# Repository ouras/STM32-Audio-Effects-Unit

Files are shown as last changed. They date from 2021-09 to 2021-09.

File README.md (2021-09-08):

# STM32-Audio-Effects-Unit

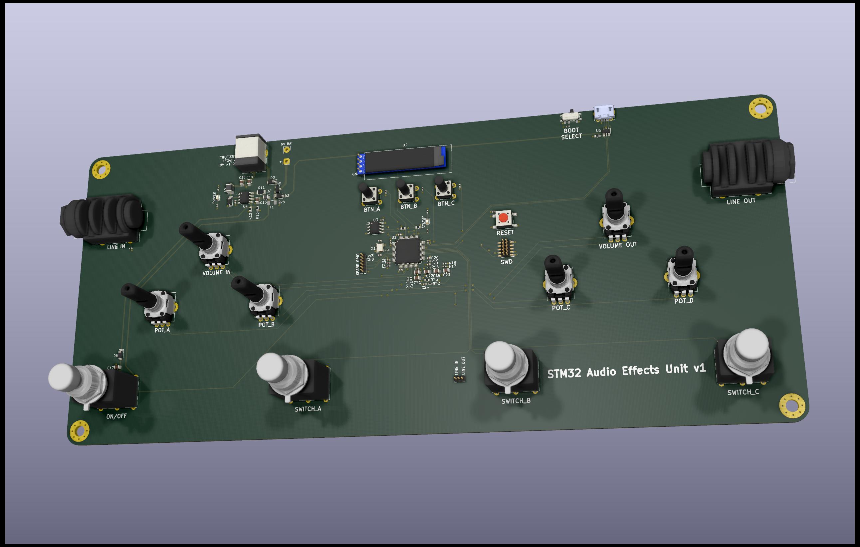
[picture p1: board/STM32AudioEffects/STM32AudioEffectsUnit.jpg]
Board v1


Audio effects unit designed for STM32. Includes:
- Library of effects implemented in C (including distortion/overdrive, reverb/echo, and compression)
- Python GUI demo/testbench for effects (based on PyQt, PyPlot, NumPy, and ctypes)
- PCB layout based on STM32F3RETx (plus LTSpice files for select sub-networks)
- CubeMX file for board (including FreeRTOS, peripheral, and pin configuration)
- main.c (FreeRTOS-based firmware)

Firmware features:
- FreeRTOS for task management
- ADC and DAC with DMA for efficient audio processing (note: sample rate = 40.5 kHz)
- I2C for EEPROM ~~and OLED display~~ *(coming soon)*
- Interrupts/handlers for user inputs

Board includes:
- 1/4" (6.35mm) input/output jacks
- OLED display
- 4 configuration potentiometers + 2 volume potentiometers
- 3 buttons
- 3 switches
- EEPROM (for user configuration backups)
- Input and output active gain and noise filter networks (with LTSpice schematics/simulation files)
- 9V DC wall adapter, 9V battery, and 5V USB power support (converted to 3.3V for Vcc)
- Status and power LEDs

Directory guide:
- /board contains LTSpice files and a KiCad project for the board
- /cubemx contains a CubeMX file for generating code for the MCU configuration and a main.c file containing the FreeRTOS port
- /demo contains files for running the demo
- /effects and /math contain the effects and math libraries
- /signal_gen_tools contains code for generating binary samples files

Running the demo:
1. Copy the contents of /demo to a folder.
2. Install the required modules (at the top of effects.py and main.py)
3. Copy the contents of /math and /effects to the folder from step 1.
4. Compile the C source files using:
  1. gcc -Wall -c fast_math.c effects.c
5. Create the shared library using:
  1. gcc -shared -o libeffects.dll \*.o
  2. Add “-m64” if using 64-bit Python
  3. Run main.py

A working document for this project (which include requirements, milestones, and technical notes) can be found [here](https://docs.google.com/document/d/13bzRhMHOJ_USe95iWY26JIxKYx1gLJ1tkpusW1AXwGo/edit?usp=sharing).

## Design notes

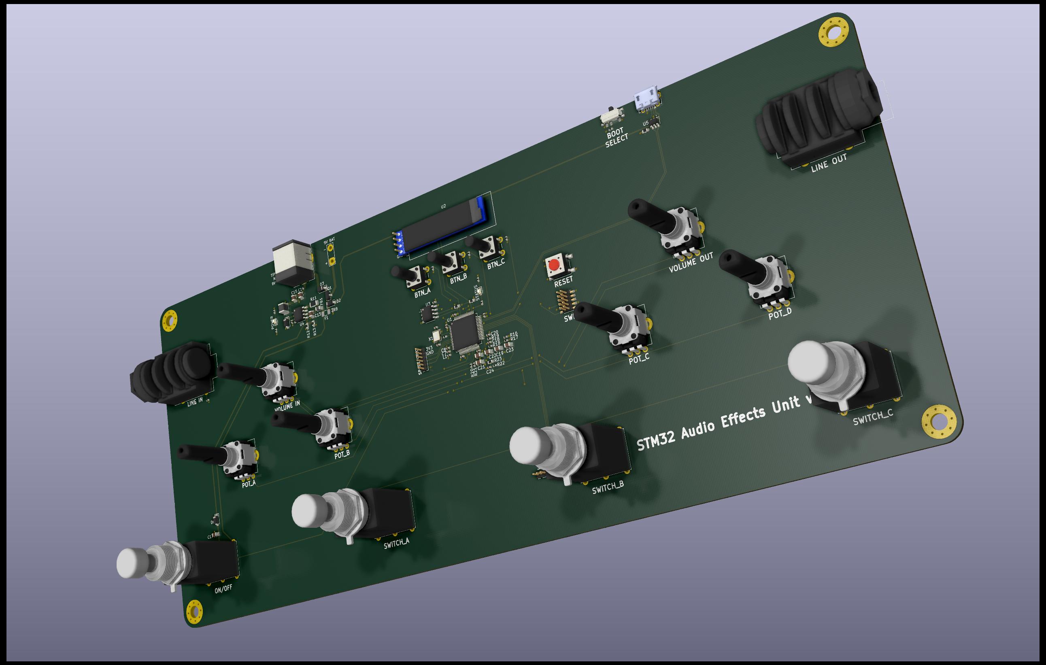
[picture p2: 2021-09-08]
board/STM32AudioEffects/STM32AudioEffects.jpg

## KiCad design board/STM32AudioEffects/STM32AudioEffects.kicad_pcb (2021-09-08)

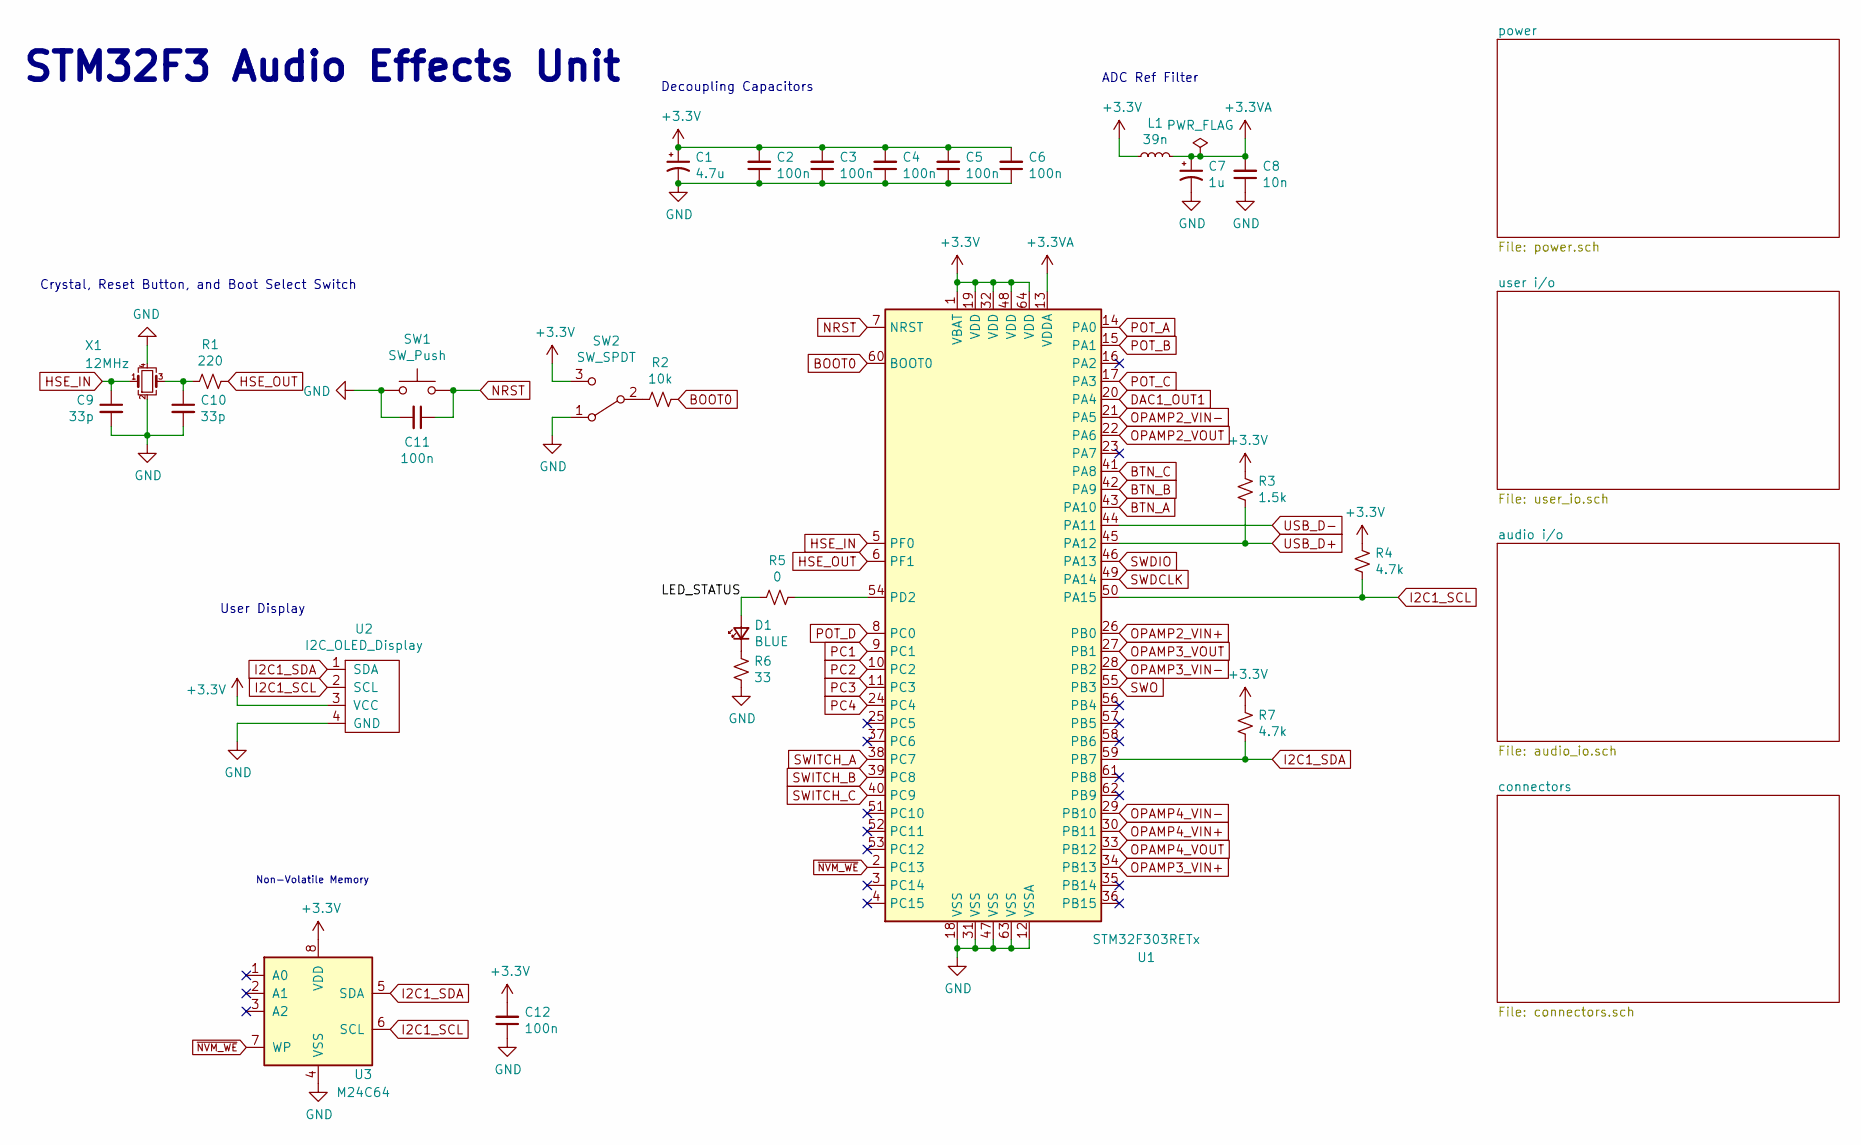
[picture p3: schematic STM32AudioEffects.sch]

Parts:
C1: 4.7u; C_0805_2012Metric
C2, C3, C4, C5, C6, C11, C12: 100n; C_0402_1005Metric
C7: 1u; C_0402_1005Metric
C8: 10n; C_0402_1005Metric
C9, C10: 33p; C_0402_1005Metric
D1: BLUE; LED_0603_1608Metric
L1: 39n; L_0402_1005Metric
R1: 220; R_0402_1005Metric
R2: 10k; R_0402_1005Metric
R3: 1.5k; R_0603_1608Metric
R4, R7: 4.7k; R_0603_1608Metric
R5: 0; R_0402_1005Metric
R6: 33; R_0402_1005Metric
SW1: SW_Push; SW_SPST_PTS645
SW2: SW_SPDT; SW_SPDT_PCM12
U1: STM32F303RETx; LQFP-64_10x10mm_P0.5mm
U2: I2C_OLED_Display; I2C_OLED_DISPLAY
U3: M24C64; SOIC-8_3.9x4.9mm_P1.27mm
X1: 12MHz; Crystal_SMD_3225-4Pin_3.2x2.5mm

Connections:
+3.3VA: C7.1, C8.2, L1.2, U1.13 (VDDA)
+3V3: C1.1, C2.2, C3.2, C4.2, C5.2, C6.2, C12.2, L1.1, R3.1, R4.1, R7.1, SW2.3 (C), U1.1 (VBAT), U1.19 (VDD), U1.32 (VDD), U1.48 (VDD), U1.64 (VDD), U2.3 (VCC), U3.8 (VDD); also elsewhere on the board
/LED_STATUS: D1.2 (A), R5.2
BOOT0: R2.1, U1.60 (BOOT0)
BTN_A: U1.43 (PA10); also elsewhere on the board
BTN_B: U1.42 (PA9); also elsewhere on the board
BTN_C: U1.41 (PA8); also elsewhere on the board
DAC1_OUT1: U1.20 (PA4); also elsewhere on the board
GND: C1.2, C2.1, C3.1, C4.1, C5.1, C6.1, C7.2, C8.1, C9.2, C10.2, C11.2, C12.1, R6.2, SW1.1, SW2.1 (A), U1.12 (VSSA), U1.18 (VSS), U1.31 (VSS), U1.47 (VSS), U1.63 (VSS), U2.4 (GND), U3.4 (VSS), X1.2, X1.4; also elsewhere on the board
HSE_IN: C9.1, U1.5 (PF0), X1.1
HSE_OUT: R1.1, U1.6 (PF1)
I2C1_SCL: R4.2, U1.50 (PA15), U2.2 (SCL), U3.6 (SCL)
I2C1_SDA: R7.2, U1.59 (PB7), U2.1 (SDA), U3.5 (SDA)
NRST: C11.1, SW1.2, U1.7 (NRST); also elsewhere on the board
unnamed: C10.1, R1.2, X1.3
unnamed: D1.1 (K), R6.1
unnamed: R2.2, SW2.2 (B)
unnamed: R5.1, U1.54 (PD2)
OPAMP2_VIN+: U1.26 (PB0); also elsewhere on the board
OPAMP3_VIN+: U1.34 (PB13); also elsewhere on the board
OPAMP3_VIN-: U1.28 (PB2); also elsewhere on the board
OPAMP3_VOUT: U1.27 (PB1); also elsewhere on the board
OPAMP4_VIN+: U1.30 (PB11); also elsewhere on the board
OPAMP4_VIN-: U1.29 (PB10), U1.33 (PB12); also elsewhere on the board
PC1: U1.9 (PC1); also elsewhere on the board
PC2: U1.10 (PC2); also elsewhere on the board
PC3: U1.11 (PC3); also elsewhere on the board
PC4: U1.24 (PC4); also elsewhere on the board
POT_A: U1.14 (PA0); also elsewhere on the board
POT_B: U1.15 (PA1); also elsewhere on the board
POT_C: U1.17 (PA3); also elsewhere on the board
POT_D: U1.8 (PC0); also elsewhere on the board
SWDCLK: U1.49 (PA14); also elsewhere on the board
SWDIO: U1.46 (PA13); also elsewhere on the board
SWITCH_A: U1.38 (PC7); also elsewhere on the board
SWITCH_B: U1.39 (PC8); also elsewhere on the board
SWITCH_C: U1.40 (PC9); also elsewhere on the board
SWO: U1.55 (PB3); also elsewhere on the board
USB_D+: R3.2, U1.45 (PA12); also elsewhere on the board
USB_D-: U1.44 (PA11); also elsewhere on the board
~NVM_WE: U1.2 (PC13), U3.7 (WP)

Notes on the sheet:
ADC Ref Filter
Decoupling Capacitors
Crystal, Reset Button, and Boot Select Switch
User Display
STM32F3 Audio Effects Unit
Non-Volatile Memory

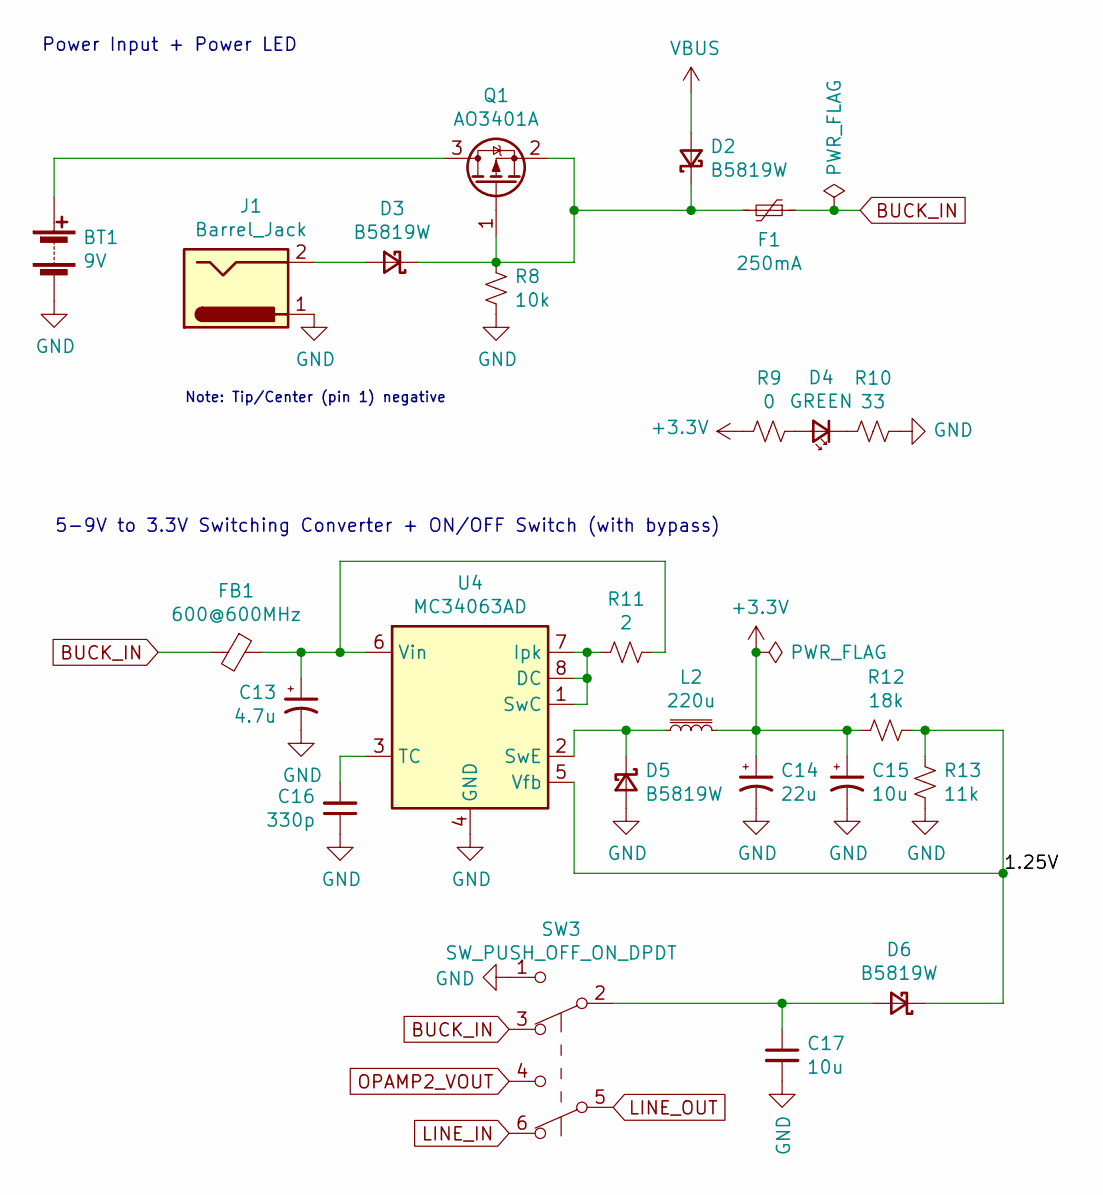
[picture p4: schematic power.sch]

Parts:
BT1: 9V; TestPoint_2Pads_Pitch5.08mm_Drill1.3mm
C13: 4.7u; C_0805_2012Metric
C14: 22u; C_0805_2012Metric
C15, C17: 10u; C_0805_2012Metric
C16: 330p; C_0402_1005Metric
D2, D3, D5, D6: B5819W; D_SOD-123
D4: GREEN; LED_0603_1608Metric
F1: 250mA; Fuse_1206_3216Metric
FB1: 600@600MHz; L_0805_2012Metric
J1: Barrel_Jack; BarrelJack_CUI_PJ-063AH_Horizontal
L2: 220u; L_1210_3225Metric
Q1: AO3401A; SOT-23
R8: 10k; R_0402_1005Metric
R9: 0; R_0402_1005Metric
R10: 33; R_0402_1005Metric
R11: 2; R_1206_3216Metric
R12: 18k; R_0603_1608Metric
R13: 11k; R_0603_1608Metric
SW3: SW_PUSH_OFF_ON_DPDT; SW_DPDT_FOOT_17.2x12.2mm_Vertical
U4: MC34063AD; SOIC-8_3.9x4.9mm_P1.27mm

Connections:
+3V3: C14.1, C15.1, L2.2, R9.1, R12.2; also elsewhere on the board
/power/1.25V: D6.1 (K), R12.1, R13.1, U4.5 (Vfb)
BUCK_IN: F1.1, FB1.2, SW3.3 (A)
GND: BT1.2 (-), C13.2, C14.2, C15.2, C16.1, C17.2, D5.2 (A), J1.1, R8.2, R10.2, R13.2, SW3.1 (C), U4.4 (GND); also elsewhere on the board
LINE_IN: SW3.6 (A); also elsewhere on the board
LINE_OUT: SW3.5 (B); also elsewhere on the board
unnamed: BT1.1 (+), Q1.3 (D)
unnamed: C13.1, FB1.1, R11.1, U4.6 (Vin)
unnamed: C16.2, U4.3 (TC)
unnamed: C17.1, D6.2 (A), SW3.2 (B)
unnamed: D2.1 (K), D3.1 (K), F1.2, Q1.1 (G), Q1.2 (S), R8.1
unnamed: D3.2 (A), J1.2
unnamed: D4.1 (K), R10.1
unnamed: D4.2 (A), R9.2
unnamed: D5.1 (K), L2.1, U4.2 (SwE)
unnamed: R11.2, U4.1 (SwC), U4.7 (Ipk), U4.8 (DC)
VBUS: D2.2 (A); also elsewhere on the board

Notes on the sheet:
Power Input + Power LED
5-9V to 3.3V Switching Converter + ON/OFF Switch (with bypass)
Note: Tip/Center (pin 1) negative

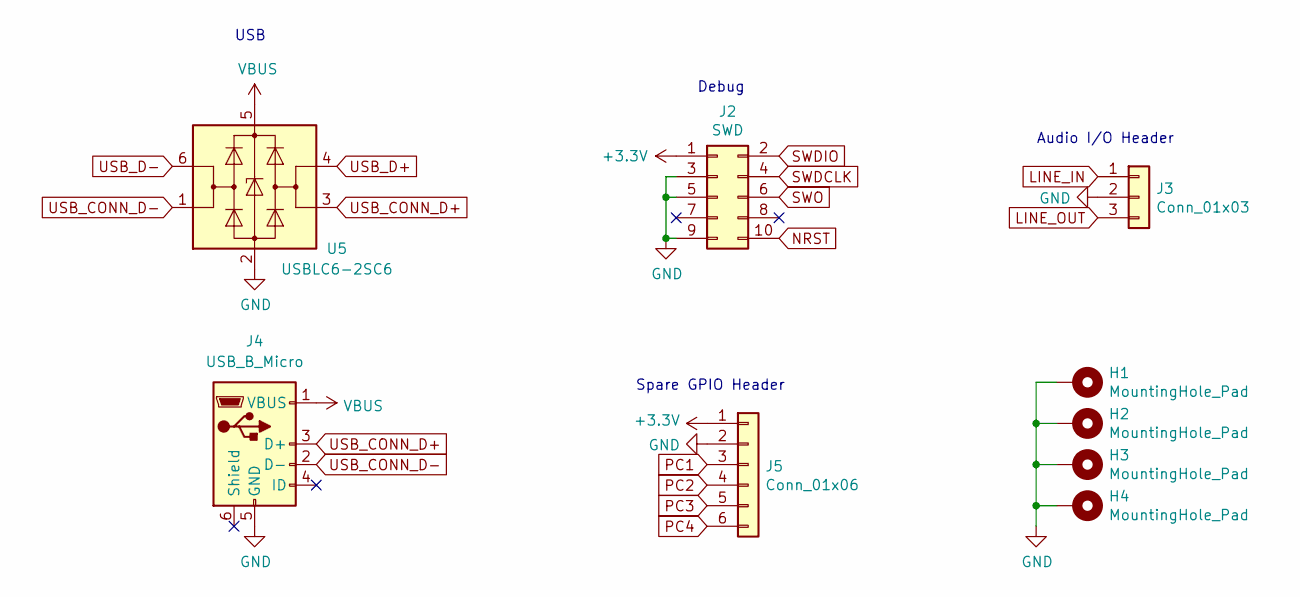
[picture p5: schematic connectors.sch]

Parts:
H1, H2, H3, H4: MountingHole_Pad; MountingHole_4.3mm_M4_Pad_Via
J2: SWD; PinHeader_2x05_P1.27mm_Vertical_SMD
J3: Conn_01x03; PinHeader_1x03_P1.27mm_Vertical
J4: USB_B_Micro; USB_Micro-B_Molex-105017-0001
J5: Conn_01x06; PinHeader_1x06_P1.27mm_Vertical
U5: USBLC6-2SC6; SOT-23-6

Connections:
+3V3: J2.1, J5.1; also elsewhere on the board
GND: H1.1, H2.1, H3.1, H4.1, J2.3, J2.5, J2.9, J3.2, J4.5 (GND), J5.2, U5.2 (GND); also elsewhere on the board
LINE_IN: J3.1; also elsewhere on the board
LINE_OUT: J3.3; also elsewhere on the board
NRST: J2.10; also elsewhere on the board
PC1: J5.3; also elsewhere on the board
PC2: J5.4; also elsewhere on the board
PC3: J5.5; also elsewhere on the board
PC4: J5.6; also elsewhere on the board
SWDCLK: J2.4; also elsewhere on the board
SWDIO: J2.2; also elsewhere on the board
SWO: J2.6; also elsewhere on the board
USB_CONN_D+: J4.3 (D+), U5.3 (I/O2)
USB_CONN_D-: J4.2 (D-), U5.1 (I/O1)
USB_D+: U5.4 (I/O2); also elsewhere on the board
USB_D-: U5.6 (I/O1); also elsewhere on the board
VBUS: J4.1 (VBUS), U5.5 (VBUS); also elsewhere on the board

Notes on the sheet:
USB
Debug
Spare GPIO Header
Audio I/O Header

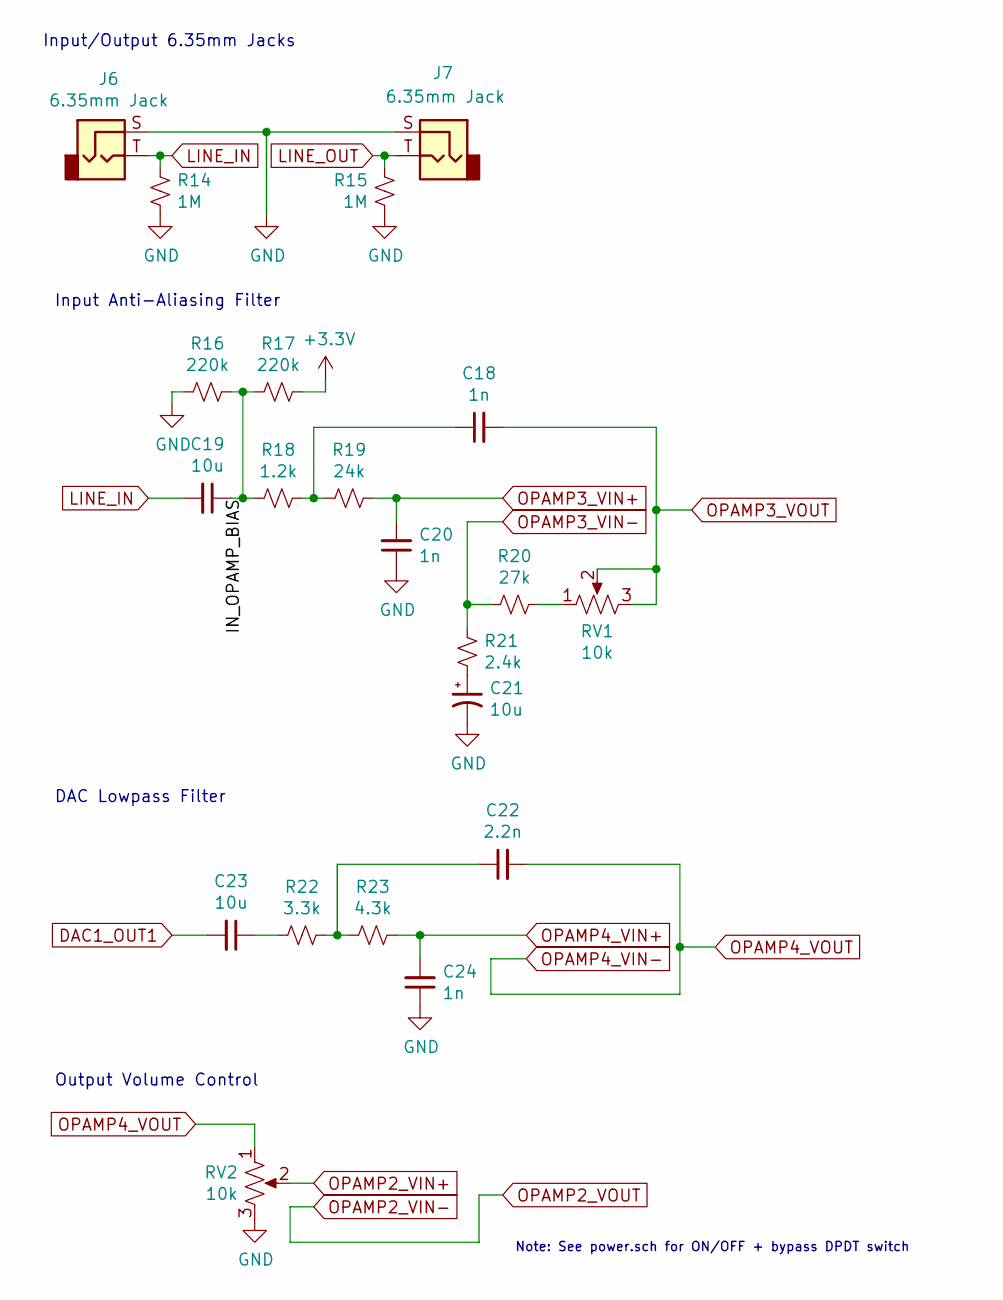
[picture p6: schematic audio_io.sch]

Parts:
C18, C20, C24: 1n; C_0402_1005Metric
C19, C21, C23: 10u; C_0805_2012Metric
C22: 2.2n; C_0805_2012Metric
J6, J7: 6.35mm Jack; Jack_6.35mm_Neutrik_NMJ4HFD2_Horizontal
R14, R15: 1M; R_0402_1005Metric
R16, R17: 220k; R_0402_1005Metric
R18: 1.2k; R_0402_1005Metric
R19: 24k; R_0402_1005Metric
R20: 27k; R_0402_1005Metric
R21: 2.4k; R_0402_1005Metric
R22: 3.3k; R_0402_1005Metric
R23: 4.3k; R_0603_1608Metric
RV1, RV2: 10k; Potentiometer_Alps_RK09K_Single_Vertical

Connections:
+3V3: R17.1; also elsewhere on the board
/audio i/o/IN_OPAMP_BIAS: C19.1, R16.1, R17.2, R18.2
DAC1_OUT1: C23.2; also elsewhere on the board
GND: C20.1, C21.2, C24.1, J6.S, J7.S, R14.2, R15.2, R16.2, RV2.3; also elsewhere on the board
LINE_IN: C19.2, J6.T, R14.1; also elsewhere on the board
LINE_OUT: J7.T, R15.1; also elsewhere on the board
unnamed: C18.1, R18.1, R19.2
unnamed: C21.1, R21.1
unnamed: C22.1, R22.1, R23.2
unnamed: C23.1, R22.2
unnamed: R20.2, RV1.1
OPAMP2_VIN+: RV2.2; also elsewhere on the board
OPAMP3_VIN+: C20.2, R19.1; also elsewhere on the board
OPAMP3_VIN-: R20.1, R21.2; also elsewhere on the board
OPAMP3_VOUT: C18.2, RV1.2, RV1.3; also elsewhere on the board
OPAMP4_VIN+: C24.2, R23.1; also elsewhere on the board
OPAMP4_VIN-: C22.2, RV2.1; also elsewhere on the board

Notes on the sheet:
Output Volume Control
DAC Lowpass Filter
Input Anti-Aliasing Filter
Input/Output 6.35mm Jacks
Note: See power.sch for ON/OFF + bypass DPDT switch

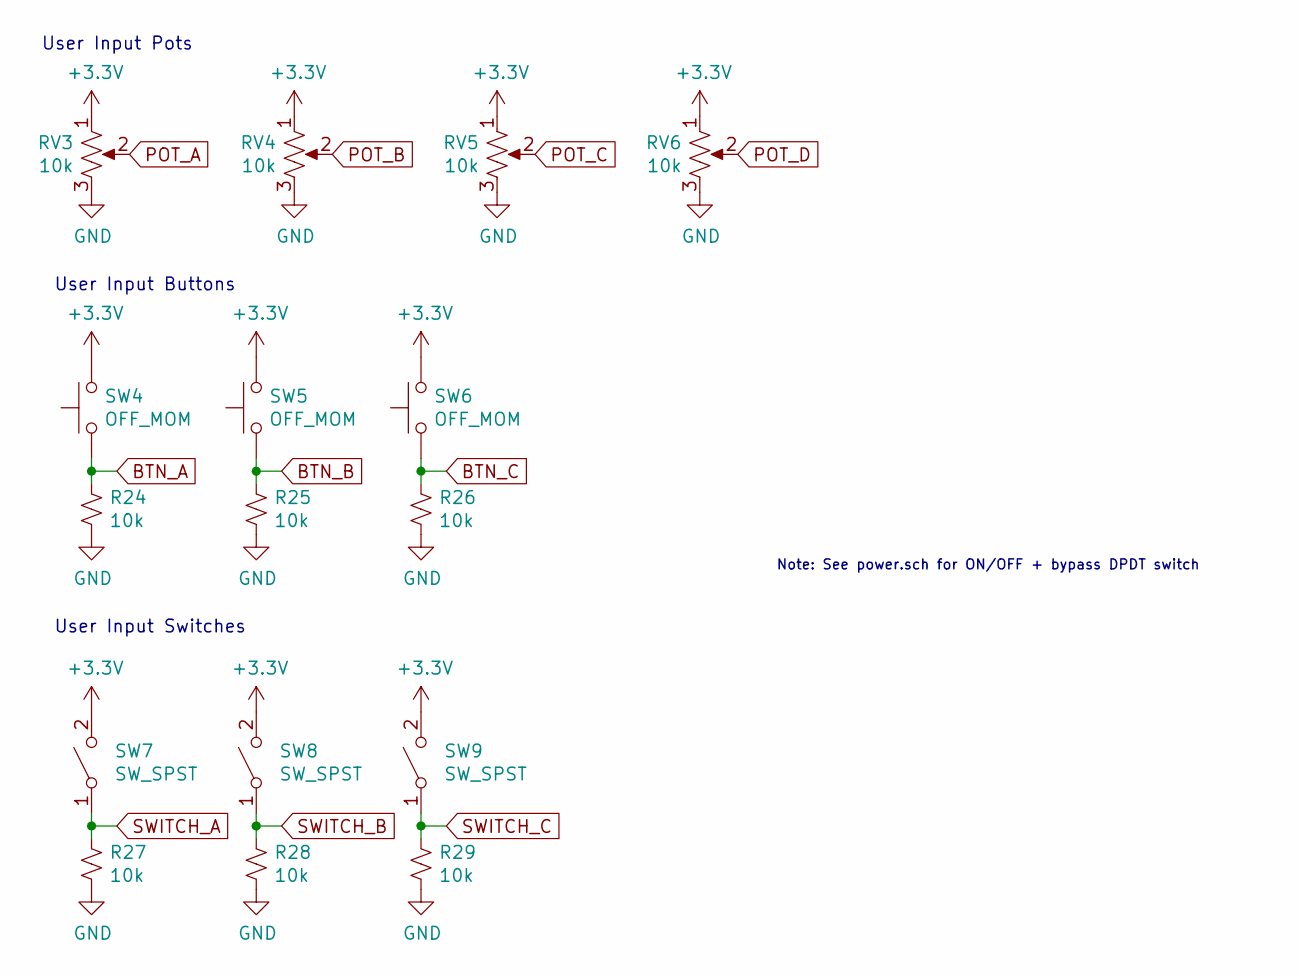
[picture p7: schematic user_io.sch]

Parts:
R24, R25, R26, R27, R28, R29: 10k; R_0402_1005Metric
RV3, RV4, RV5, RV6: 10k; Potentiometer_Alps_RK09K_Single_Vertical
SW4, SW5, SW6: OFF_MOM; SW_PUSH_6mm_H13mm
SW7, SW8, SW9: SW_SPST; SW_DPDT_FOOT_17.2x12.2mm_Vertical

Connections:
+3V3: RV3.1, RV4.1, RV5.1, RV6.1, SW4.2, SW5.2, SW6.2, SW7.2 (B), SW8.2 (B), SW9.2 (B); also elsewhere on the board
BTN_A: R24.2, SW4.1; also elsewhere on the board
BTN_B: R25.2, SW5.1; also elsewhere on the board
BTN_C: R26.2, SW6.1; also elsewhere on the board
GND: R24.1, R25.1, R26.1, R27.1, R28.1, R29.1, RV3.3, RV4.3, RV5.3, RV6.3; also elsewhere on the board
POT_A: RV3.2; also elsewhere on the board
POT_B: RV4.2; also elsewhere on the board
POT_C: RV5.2; also elsewhere on the board
POT_D: RV6.2; also elsewhere on the board
SWITCH_A: R27.2, SW7.1 (A); also elsewhere on the board
SWITCH_B: R28.2, SW8.1 (A); also elsewhere on the board
SWITCH_C: R29.2, SW9.1 (A); also elsewhere on the board

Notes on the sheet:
User Input Pots
User Input Buttons
User Input Switches
Note: See power.sch for ON/OFF + bypass DPDT switch

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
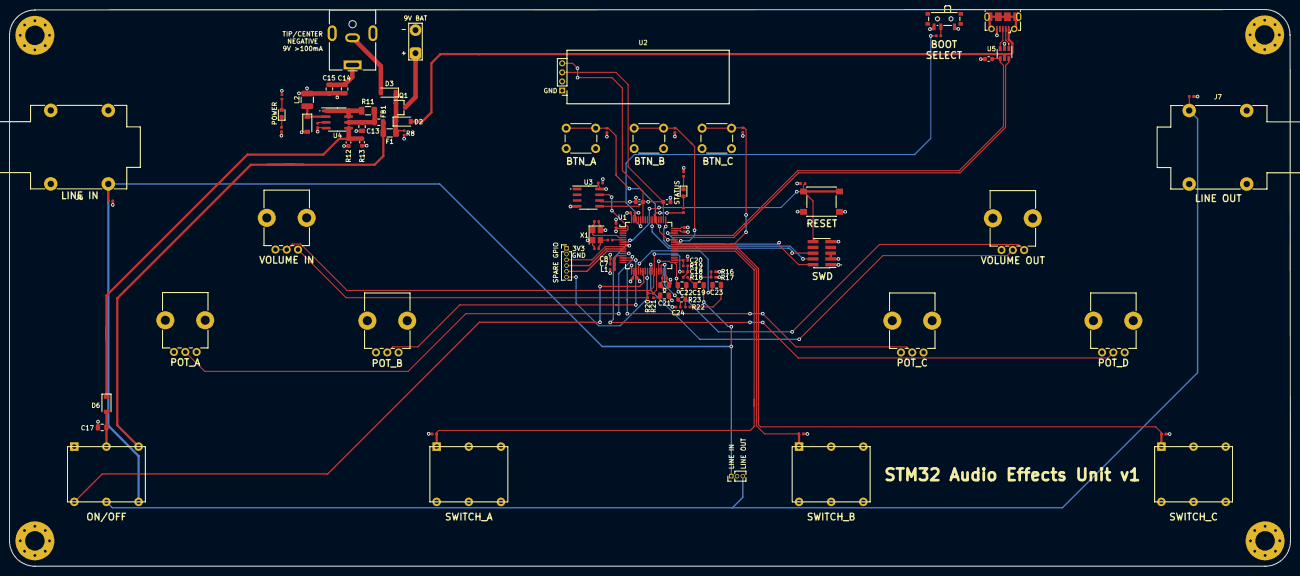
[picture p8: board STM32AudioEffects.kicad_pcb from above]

Board: 4 copper layers, 282.8 x 122.9 mm, 97 parts (0 on the bottom side), 65 nets.

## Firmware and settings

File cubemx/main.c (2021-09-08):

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
/* Includes ------------------------------------------------------------------*/
#include "main.h"
#include "cmsis_os.h"

/* USER CODE BEGIN Includes */
#include <stdbool.h>
#include <string.h>
#include "effects.h"
/* USER CODE END Includes */

/* USER CODE BEGIN PTD */

#define NUM_EFFECTS 3

typedef enum
{
	OVERDRIVE,
	ECHO,
	COMPRESSION,
} Effect;

typedef struct
{
	Effect ordered[NUM_EFFECTS];		// Active effects in order
	bool isEnabled[NUM_EFFECTS];		// Whether each active effect is enabled (indexable by ordered)
	uint8_t activeEffectSelection;	// Which effect is currently selected (i.e., an index of ordered)
} EffectsState;

typedef struct
{
	/* Effects configurations */
	OverdriveParam overdrive;
	EchoParam echo;
	CompressionParam compression;
	
	/* Effects limits (min and max values for each effect, corresponding to each end of pot) */
	OverdriveParam overdriveMin, overdriveMax;
	EchoParam echoMin, echoMax;
	CompressionParam compressionMin, compressionMax;
} EffectsParams;

typedef struct
{
	osThreadId sourceTask;
	bool rxTxBar;					// Set to true if receive is enabled, false if transmit is enabled
	uint16_t address;			// Receiving device address
	uint8_t *pPayload;		// Pointer to payload buffer
	uint16_t items;				// Number of items in payload buffer
	bool *pFailed;				// Indicates whether message was dropped or not at any point in transmission
} I2CMessage;

/* USER CODE END PTD */

/* USER CODE BEGIN PD */

/* Data convention definitions */
#ifndef X_AXIS
#define X_AXIS (UINT16_MAX / 2)	// x-axis, the median representable signal using uint16
#endif

#ifndef FIXED_POINT_Q
#define FIXED_POINT_Q 8	// N in QN for fixed-point numbers
#endif

/* Buffer size definitions */
#define SAMPLE_BUF_LEN 405								// One buffer of samples (same size for both ADC and DAC
#define ADC_BUF_LEN (2 * SAMPLE_BUF_LEN)	// Ping-pong buffer (circular buffer of 2 buffers)
#define DAC_BUF_LEN ADC_BUF_LEN						// Each ADC buffer has a corresponding DAC buffer for processed samples

#define NUM_DELAY_SAMPLES MAX_ECHO_DELAY_SAMPLES	// Number of extra delayed samples for echo

/* I2C Device Addresses */
#define DISPLAY_I2C_ADDR 0x3C
#define ROM_I2C_ADDR 0xA0

/* USER CODE END PD */

ADC_HandleTypeDef hadc1;
ADC_HandleTypeDef hadc3;
DMA_HandleTypeDef hdma_adc3;

DAC_HandleTypeDef hdac1;
DMA_HandleTypeDef hdma_dac1_ch1;

I2C_HandleTypeDef hi2c1;

OPAMP_HandleTypeDef hopamp2;
OPAMP_HandleTypeDef hopamp3;
OPAMP_HandleTypeDef hopamp4;

TIM_HandleTypeDef htim2;

PCD_HandleTypeDef hpcd_USB_FS;

DMA_HandleTypeDef hdma_memtomem_dma1_channel1;
osThreadId effectsTaskHandle;
uint32_t effectsTaskBuffer[ 128 ];
osStaticThreadDef_t effectsTaskControlBlock;
osThreadId btnHandlerTaskHandle;
uint32_t btnHandlerTaskBuffer[ 128 ];
osStaticThreadDef_t btnHandlerTaskControlBlock;
osThreadId swHandlerTaskHandle;
uint32_t swHandlerTaskBuffer[ 128 ];
osStaticThreadDef_t swHandlerTaskControlBlock;
osThreadId potHandlerTaskHandle;
uint32_t potHandlerTaskBuffer[ 128 ];
osStaticThreadDef_t potHandlerTaskControlBlock;
osThreadId ledTaskHandle;
uint32_t ledTaskBuffer[ 128 ];
osStaticThreadDef_t ledTaskControlBlock;
osThreadId i2cHandlerTaskHandle;
uint32_t i2cHandlerTaskBuffer[ 128 ];
osStaticThreadDef_t i2cHandlerTaskControlBlock;
osThreadId romHandlerTaskHandle;
uint32_t romHandlerTaskBuffer[ 128 ];
osStaticThreadDef_t romHandlerTaskControlBlock;
osThreadId displayHandlerTaskHandle;
uint32_t displayHandlerTaskBuffer[ 128 ];
osStaticThreadDef_t displayHandlerTaskControlBlock;
osMessageQId i2cQueueHandle;
uint8_t i2cQueueBuffer[ 16 * sizeof( I2CMessage ) ];
osStaticMessageQDef_t i2cQueueControlBlock;
osMessageQId displayCommandQueueHandle;
uint8_t displayCommandQueueBuffer[ 16 * sizeof( uint16_t ) ];
osStaticMessageQDef_t displayCommandQueueControlBlock;
osSemaphoreId delaySamplesDmaSemaphoreHandle;
osStaticSemaphoreDef_t delaySamplesDmaSemaphoreControlBlock;
osSemaphoreId i2cCompletionSemaphoreHandle;
osStaticSemaphoreDef_t i2cCompletionSemaphoreControlBlock;
osSemaphoreId i2cFailedRomSemaphoreHandle;
osStaticSemaphoreDef_t i2cFailedRomSemaphoreControlBlock;
osSemaphoreId i2cFailedDisplaySemaphoreHandle;
osStaticSemaphoreDef_t i2cFailedDisplaySemaphoreControlBlock;
/* USER CODE BEGIN PV */

/* Structure to keep track of the effects group configuration state */
static volatile EffectsState effectsState;

/* Structure to manage individual effects' configurations (including min/max values) */
static volatile EffectsParams effectsParams;

/* DMA buffer for ADC samples (note: samples are in order of decreasing age) */
static volatile uint16_t adcBuf[ADC_BUF_LEN] = {0};

/* Pointers to each half of ADC/DMA buffer for ping-pong buffering
		(note: DMA sees one buffer, alternating between the two) */
static volatile uint16_t* const adcBufA = adcBuf;
static volatile uint16_t* const adcBufB = &adcBuf[SAMPLE_BUF_LEN];

/* Extra buffer for carrying over enough past samples for echo.
		Note: This is constantly filled with last NUM_DELAY_SAMPLES samples, regardless of echo configuration */
static volatile uint16_t delaySamplesBuf[NUM_DELAY_SAMPLES] = {0};

/* Buffer for filter outputs (note: samples are in order of decreasing age) */
static volatile uint16_t dacBuf[DAC_BUF_LEN] = {0};

/* Pointers to each half of the output buffer, either buffer may be used at a time */
static volatile uint16_t* const dacBufA = dacBuf;
static volatile uint16_t* const dacBufB = &dacBuf[DAC_BUF_LEN / 2];

/* USER CODE END PV */

void SystemClock_Config(void);
static void MX_GPIO_Init(void);
static void MX_DMA_Init(void);
static void MX_DAC1_Init(void);
static void MX_OPAMP2_Init(void);
static void MX_TIM2_Init(void);
static void MX_USB_PCD_Init(void);
static void MX_ADC1_Init(void);
static void MX_OPAMP3_Init(void);
static void MX_I2C1_Init(void);
static void MX_OPAMP4_Init(void);
static void MX_ADC3_Init(void);
void startEffectsTask(void const * argument);
void startBtnHandlerTask(void const * argument);
void startSwHandlerTask(void const * argument);
void startPotHandlerTask(void const * argument);
void startLedTask(void const * argument);
void startI2cHandlerTask(void const * argument);
void startRomHandlerTask(void const * argument);
void startDisplayHandlerTask(void const * argument);

/**
  * @brief  The application entry point.
  * @retval int
  */
int main(void)
{
  /* MCU Configuration--------------------------------------------------------*/

  /* Reset of all peripherals, Initializes the Flash interface and the Systick. */
  HAL_Init();

  /* Configure the system clock */
  SystemClock_Config();

  /* Initialize all configured peripherals */
  MX_GPIO_Init();
  MX_DMA_Init();
  MX_DAC1_Init();
  MX_OPAMP2_Init();
  MX_TIM2_Init();
  MX_USB_PCD_Init();
  MX_ADC1_Init();
  MX_OPAMP3_Init();
  MX_I2C1_Init();
  MX_OPAMP4_Init();
  MX_ADC3_Init();
  /* USER CODE BEGIN RTOS_MUTEX */
  /* add mutexes, ... */
  /* USER CODE END RTOS_MUTEX */

  /* Create the semaphores(s) */
  /* definition and creation of delaySamplesDmaSemaphore */
  osSemaphoreStaticDef(delaySamplesDmaSemaphore, &delaySamplesDmaSemaphoreControlBlock);
  delaySamplesDmaSemaphoreHandle = osSemaphoreCreate(osSemaphore(delaySamplesDmaSemaphore), 1);

  /* definition and creation of i2cCompletionSemaphore */
  osSemaphoreStaticDef(i2cCompletionSemaphore, &i2cCompletionSemaphoreControlBlock);
  i2cCompletionSemaphoreHandle = osSemaphoreCreate(osSemaphore(i2cCompletionSemaphore), 1);

  /* definition and creation of i2cFailedRomSemaphore */
  osSemaphoreStaticDef(i2cFailedRomSemaphore, &i2cFailedRomSemaphoreControlBlock);
  i2cFailedRomSemaphoreHandle = osSemaphoreCreate(osSemaphore(i2cFailedRomSemaphore), 1);

  /* definition and creation of i2cFailedDisplaySemaphore */
  osSemaphoreStaticDef(i2cFailedDisplaySemaphore, &i2cFailedDisplaySemaphoreControlBlock);
  i2cFailedDisplaySemaphoreHandle = osSemaphoreCreate(osSemaphore(i2cFailedDisplaySemaphore), 1);

  /* USER CODE BEGIN RTOS_SEMAPHORES */
  /* add semaphores, ... */
  /* USER CODE END RTOS_SEMAPHORES */

  /* USER CODE BEGIN RTOS_TIMERS */
  /* start timers, add new ones, ... */
  /* USER CODE END RTOS_TIMERS */

  /* Create the queue(s) */
  /* definition and creation of i2cQueue */
  osMessageQStaticDef(i2cQueue, 16, I2CMessage, i2cQueueBuffer, &i2cQueueControlBlock);
  i2cQueueHandle = osMessageCreate(osMessageQ(i2cQueue), NULL);

  /* definition and creation of displayCommandQueue */
  osMessageQStaticDef(displayCommandQueue, 16, uint16_t, displayCommandQueueBuffer, &displayCommandQueueControlBlock);
  displayCommandQueueHandle = osMessageCreate(osMessageQ(displayCommandQueue), NULL);

  /* USER CODE BEGIN RTOS_QUEUES */
  /* add queues, ... */
  /* USER CODE END RTOS_QUEUES */

  /* Create the thread(s) */
  /* definition and creation of effectsTask */
  osThreadStaticDef(effectsTask, startEffectsTask, osPriorityRealtime, 0, 128, effectsTaskBuffer, &effectsTaskControlBlock);
  effectsTaskHandle = osThreadCreate(osThread(effectsTask), NULL);

  /* definition and creation of btnHandlerTask */
  osThreadStaticDef(btnHandlerTask, startBtnHandlerTask, osPriorityNormal, 0, 128, btnHandlerTaskBuffer, &btnHandlerTaskControlBlock);
  btnHandlerTaskHandle = osThreadCreate(osThread(btnHandlerTask), NULL);

  /* definition and creation of swHandlerTask */
  osThreadStaticDef(swHandlerTask, startSwHandlerTask, osPriorityNormal, 0, 128, swHandlerTaskBuffer, &swHandlerTaskControlBlock);
  swHandlerTaskHandle = osThreadCreate(osThread(swHandlerTask), NULL);

  /* definition and creation of potHandlerTask */
  osThreadStaticDef(potHandlerTask, startPotHandlerTask, osPriorityNormal, 0, 128, potHandlerTaskBuffer, &potHandlerTaskControlBlock);
  potHandlerTaskHandle = osThreadCreate(osThread(potHandlerTask), NULL);

  /* definition and creation of ledTask */
  osThreadStaticDef(ledTask, startLedTask, osPriorityNormal, 0, 128, ledTaskBuffer, &ledTaskControlBlock);
  ledTaskHandle = osThreadCreate(osThread(ledTask), NULL);

  /* definition and creation of i2cHandlerTask */
  osThreadStaticDef(i2cHandlerTask, startI2cHandlerTask, osPriorityNormal, 0, 128, i2cHandlerTaskBuffer, &i2cHandlerTaskControlBlock);
  i2cHandlerTaskHandle = osThreadCreate(osThread(i2cHandlerTask), NULL);

  /* definition and creation of romHandlerTask */
  osThreadStaticDef(romHandlerTask, startRomHandlerTask, osPriorityNormal, 0, 128, romHandlerTaskBuffer, &romHandlerTaskControlBlock);
  romHandlerTaskHandle = osThreadCreate(osThread(romHandlerTask), NULL);

  /* definition and creation of displayHandlerTask */
  osThreadStaticDef(displayHandlerTask, startDisplayHandlerTask, osPriorityNormal, 0, 128, displayHandlerTaskBuffer, &displayHandlerTaskControlBlock);
  displayHandlerTaskHandle = osThreadCreate(osThread(displayHandlerTask), NULL);

  /* USER CODE BEGIN RTOS_THREADS */
  /* add threads, ... */
  /* USER CODE END RTOS_THREADS */

  /* Start scheduler */
  osKernelStart();

  /* We should never get here as control is now taken by the scheduler */
  /* Infinite loop */
  /* USER CODE BEGIN WHILE */
  while (1)
  {
    /* USER CODE END WHILE */

    /* USER CODE BEGIN 3 */
  }
  /* USER CODE END 3 */
}

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
/* USER CODE BEGIN 4 */

void HAL_GPIO_EXTI_Callback(uint16_t GPIO_Pin)
{
	xTaskNotifyFromISR(btnHandlerTaskHandle, GPIO_Pin, eSetValueWithOverwrite, NULL);
}

void HAL_ADC_ConvHalfCpltCallback(ADC_HandleTypeDef* hadc)
{
	if (hadc == &hadc3)
	{
		xTaskNotifyFromISR(effectsTaskHandle, (uint32_t) adcBufA, eSetValueWithOverwrite, NULL);
	}
}

void HAL_ADC_ConvCpltCallback(ADC_HandleTypeDef* hadc)
{
	if (hadc == &hadc1)
	{
		xTaskNotifyFromISR(potHandlerTaskHandle, HAL_ADC_GetValue(hadc), eSetValueWithOverwrite, NULL);
	}
	else if (hadc == &hadc3)
	{
		xTaskNotifyFromISR(effectsTaskHandle, (uint32_t) adcBufB, eSetValueWithOverwrite, NULL);
	}
}

void HAL_DAC_ConvHalfCpltCallbackCh1(DAC_HandleTypeDef* hdac)
{
	xTaskNotifyFromISR(effectsTaskHandle, (uint32_t) dacBufA, eSetValueWithOverwrite, NULL);
}
	
void HAL_DAC_ConvCpltCallbackCh1(DAC_HandleTypeDef* hdac)
{
	xTaskNotifyFromISR(effectsTaskHandle, (uint32_t) dacBufB, eSetValueWithOverwrite, NULL);
}

void HAL_DMA_CpltCallback(DMA_HandleTypeDef* hdma)
{
	if (hdma == &hdma_memtomem_dma1_channel1)
	{
		xSemaphoreGiveFromISR(delaySamplesDmaSemaphoreHandle, NULL);
	}
}
/* USER CODE END 4 */

/* USER CODE BEGIN Header_startEffectsTask */
/**
  * @brief  Function implementing the effectsTask thread.
  * @param  argument: Not used
  * @retval None
  */
/* USER CODE END Header_startEffectsTask */
void startEffectsTask(void const * argument)
{
  /* USER CODE BEGIN 5 */
	
	/* Start ADC and DAC. Note: ADC expects buffers to be ready to be filled,
			DAC expects buffers to be ready to be read from. Software must ensure this. */
	HAL_ADC_Start_DMA(&hadc3, (uint32_t *) adcBuf, ADC_BUF_LEN);
	HAL_DAC_Start_DMA(&hdac1, DAC_CHANNEL_1, (uint32_t *) dacBuf, DAC_BUF_LEN, DAC_ALIGN_12B_R);
	HAL_TIM_OC_Start(&htim2, TIM_CHANNEL_1);
	
  /* Infinite loop */
  for(;;)
  {
		uint16_t *currAdcBuf;
		uint16_t *currDacBuf;
		
		uint16_t *echoInputBuf;
		uint16_t *inputBuf;
		uint16_t *outputBuf;
		uint16_t *temp;
		
		/* To preserve effects for delayed samples (which are added for echo), they must be processed as well.
				echoDelaySamplesBuf is used for processing the delayed samples. */
		uint16_t *echoDelaySamplesBuf;
		
		/* Effects state and params must be latched before processing so they remain consistent for the whole buffer */
		EffectsState latchedEffectsState;
		EffectsParams latchedEffectsParams;
		
		/* DAC takes ticksToWait ticks to output a buffer before starting the next one.
				If software does not finish the next buffer before that time, the DAC outputs invalid data,
				so must give up and wait for next ADC buffer. */
		const uint16_t samplingPeriodUs = 25;	// Sampling period in microseconds
		TickType_t ticksToWait = pdMS_TO_TICKS(samplingPeriodUs * SAMPLE_BUF_LEN / 1000) - pdMS_TO_TICKS(2);	// Subtract some time to account for processing
		TimeOut_t timeOut;
		
		/* Wait for ADC buffer (and make sure it is an ADC buffer) */
		currAdcBuf = (uint16_t *) ulTaskNotifyTake(pdTRUE, portMAX_DELAY);
		
		if (currAdcBuf != adcBufA && currAdcBuf != adcBufB)
		{
			continue;
		}
		
		/* Add ADC samples to delaySamplesBuf (must shift current samples first, then insert at end) */
		HAL_DMA_Start_IT(&hdma_memtomem_dma1_channel1, (uint32_t) &delaySamplesBuf[SAMPLE_BUF_LEN], (uint32_t) delaySamplesBuf, NUM_DELAY_SAMPLES - SAMPLE_BUF_LEN);
		
		if (xSemaphoreTake(delaySamplesDmaSemaphoreHandle, ticksToWait) != pdTRUE)
		{
			continue;
		}
		
		HAL_DMA_Start(&hdma_memtomem_dma1_channel1, (uint32_t) currAdcBuf, (uint32_t) &delaySamplesBuf[NUM_DELAY_SAMPLES - SAMPLE_BUF_LEN], NUM_DELAY_SAMPLES);
		
		/* Wait for DAC buffer (with timeout, and make sure it is a DAC buffer) */
		vTaskSetTimeOutState(&timeOut);
		currDacBuf = (uint16_t *) ulTaskNotifyTake(pdTRUE, ticksToWait);
		
		if (xTaskCheckForTimeOut(&timeOut, &ticksToWait) == pdTRUE)
		{
			continue;
		}
		
		if (currDacBuf != dacBufA && currDacBuf != dacBufB)
		{
			continue;
		}
		
		/* Allocate echoDelaySamplesBuf and copy over delaySamplesBuf */
		echoDelaySamplesBuf = (uint16_t *) pvPortMalloc(NUM_DELAY_SAMPLES * sizeof(uint16_t));
		
		HAL_DMA_Start_IT(&hdma_memtomem_dma1_channel1, (uint32_t) delaySamplesBuf, (uint32_t) echoDelaySamplesBuf, NUM_DELAY_SAMPLES);
		
		if (xSemaphoreTake(delaySamplesDmaSemaphoreHandle, ticksToWait) != pdTRUE)
		{
			continue;
		}
		
		/* Apply effects (in order) to inputBuf, storing in outputBuf.
				inputBuf and outputBuf atart as the ADC and DAC buffers respectively. */
		inputBuf = currAdcBuf;
		outputBuf = currDacBuf;
		
		latchedEffectsState = effectsState;
		latchedEffectsParams = effectsParams;
		
		for (int i = 0; i < 3; i++)
		{
			Effect effect = latchedEffectsState.ordered[i];
			
			if (latchedEffectsState.isEnabled[effect])
			{
				/* If the effect is echo, echoInputBuf must be prepared by
						concatenating echoDelaySamples to inputBuf in a new buffer */
				if (effect == ECHO)
				{
					size_t numDelaySamples = latchedEffectsParams.echo.delay_samples;	// Number of delayed samples needed (i.e., if index 0 represent n = 0 for signal x[n], x[-numDelaySamples] is the oldest sample)
					
					echoInputBuf = pvPortMalloc((numDelaySamples + SAMPLE_BUF_LEN) * sizeof(uint16_t));
					
					HAL_DMA_Start_IT(&hdma_memtomem_dma1_channel1, (uint32_t) &echoDelaySamplesBuf[NUM_DELAY_SAMPLES - numDelaySamples], (uint32_t) echoInputBuf, numDelaySamples);
					
					if (xSemaphoreTake(delaySamplesDmaSemaphoreHandle, ticksToWait) != pdTRUE)
					{
						continue;
					}
					
					HAL_DMA_Start_IT(&hdma_memtomem_dma1_channel1, (uint32_t) inputBuf, (uint32_t) &echoInputBuf[numDelaySamples], SAMPLE_BUF_LEN);
					
					if (xSemaphoreTake(delaySamplesDmaSemaphoreHandle, ticksToWait) != pdTRUE)
					{
						continue;
					}
				}
				
				/* Apply appropriate effect */
				switch (effect)
				{
					case OVERDRIVE: 	buf_overdrive(inputBuf, outputBuf, SAMPLE_BUF_LEN, &latchedEffectsParams.overdrive); break;
					case ECHO:				buf_echo(echoInputBuf, outputBuf, SAMPLE_BUF_LEN, &latchedEffectsParams.echo); break;
					case COMPRESSION:	buf_compression(inputBuf, outputBuf, SAMPLE_BUF_LEN, &latchedEffectsParams.compression); break;
					default: break;
				}
				
				/* If echo is enabled but not the first effect, also apply effect to delayed samples (echoDelaySamplesBuf).
						This only needs to be done so echoes of delayed samples are consistent with non-delayed samples.*/
				if (latchedEffectsState.isEnabled[ECHO] && latchedEffectsState.ordered[0] != ECHO)
				{
					/* Note: ECHO is ommitted since an effect can only appear once */
					switch (effect)
					{
						case OVERDRIVE: 	buf_overdrive(echoDelaySamplesBuf, echoDelaySamplesBuf, NUM_DELAY_SAMPLES, &latchedEffectsParams.overdrive); break;
						case COMPRESSION:	buf_compression(echoDelaySamplesBuf, echoDelaySamplesBuf, NUM_DELAY_SAMPLES, &latchedEffectsParams.compression); break;
						default: break;
					}
					
					if (effect == ECHO)
					{
						vPortFree(echoDelaySamplesBuf);
					}
				}
				
				/* Swap inputBuf and outputBuf. Since effects are applied sequentially,
						outputBuf becomes the input for the next effect. */
				temp = inputBuf;
				inputBuf = outputBuf;
				outputBuf = temp;
			}
		}
		
		/* If outputBuf is not the DAC buffer (i.e., the DAC buffer does not
				have the final output), copy outputBuf to dacBuf */
		if (outputBuf != dacBuf)
		{
			memcpy(currDacBuf, outputBuf, (DAC_BUF_LEN / 2) * sizeof(uint16_t));
		}
  }
  /* USER CODE END 5 */
}

/* USER CODE BEGIN Header_startBtnHandlerTask */
/**
* @brief Function implementing the btnHandlerTask thread.
* @param argument: Not used
* @retval None
*/
/* USER CODE END Header_startBtnHandlerTask */
void startBtnHandlerTask(void const * argument)
{
  /* USER CODE BEGIN startBtnHandlerTask */
  /* Infinite loop */
  for(;;)
  {
		/* Wait for interrupt from button */
		uint16_t pin = ulTaskNotifyTake(pdTRUE, portMAX_DELAY);
		
		switch (pin)
		{
			case BTN_A_Pin:
			{
			
			} break;
			case BTN_B_Pin:
			{
			
			} break;
			case BTN_C_Pin:
			{
			
			} break;
			default: break;
		}
  }
  /* USER CODE END startBtnHandlerTask */
}

/* USER CODE BEGIN Header_startSwHandlerTask */
/**
* @brief Function implementing the swHandlerTask thread.
* @param argument: Not used
* @retval None
*/
/* USER CODE END Header_startSwHandlerTask */
void startSwHandlerTask(void const * argument)
{
  /* USER CODE BEGIN startSwHandlerTask */
	uint16_t pollingFrequencyMs = 5;
	
  /* Infinite loop */
  for(;;)
  {
		Effect effect_a = effectsState.ordered[0];
		Effect effect_b = effectsState.ordered[1];
		Effect effect_c = effectsState.ordered[2];
		
		effectsState.isEnabled[effect_a] = HAL_GPIO_ReadPin(SWITCH_A_GPIO_Port, SWITCH_A_Pin) == GPIO_PIN_SET;
		effectsState.isEnabled[effect_b] = HAL_GPIO_ReadPin(SWITCH_A_GPIO_Port, SWITCH_B_Pin) == GPIO_PIN_SET;
		effectsState.isEnabled[effect_c] = HAL_GPIO_ReadPin(SWITCH_A_GPIO_Port, SWITCH_C_Pin) == GPIO_PIN_SET;

		osDelay(pollingFrequencyMs);
  }
  /* USER CODE END startSwHandlerTask */
}
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

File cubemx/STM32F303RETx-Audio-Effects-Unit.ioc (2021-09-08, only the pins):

Mcu.UserName=STM32F303RETx
PA0.GPIO_Label=POT_A
PA0.Signal=ADC1_IN1
PA1.GPIO_Label=POT_B
PA1.Signal=ADC1_IN2
PA10.GPIO_Label=BTN_A
PA10.Signal=GPXTI10
PA11.Signal=USB_DM
PA12.Signal=USB_DP
PA13.Signal=SYS_JTMS-SWDIO
PA14.Signal=SYS_JTCK-SWCLK
PA15.Signal=I2C1_SCL
PA3.GPIO_Label=POT_C
PA3.Signal=ADC1_IN4
PA4.Signal=COMP_DAC11_group
PA5.Signal=OPAMP2_VINM
PA6.Signal=OPAMP2_VOUT
PA8.GPIO_Label=BTN_C
PA8.Signal=GPXTI8
PA9.GPIO_Label=BTN_B
PA9.Signal=GPXTI9
PB0.Signal=OPAMP2_VINP
PB1.Signal=OPAMP3_VOUT
PB10.Signal=OPAMP4_VINM
PB11.Signal=OPAMP4_VINP
PB12.Signal=OPAMP4_VOUT
PB13.Signal=OPAMP3_VINP
PB2.Signal=OPAMP3_VINM
PB3.Signal=SYS_JTDO-TRACESWO
PB7.Signal=I2C1_SDA
PC0.GPIO_Label=POT_D
PC0.Signal=ADCx_IN6
PC13.GPIO_Label=nNVM_WE
PC13.Signal=GPIO_Output
PC6.GPIO_Label=STATUS_LED
PC6.Signal=GPIO_Output
PC7.GPIO_Label=SWITCH_A
PC7.Signal=GPIO_Input
PC8.GPIO_Label=SWITCH_B
PC8.Signal=GPIO_Input
PC9.GPIO_Label=SWITCH_C
PC9.Signal=GPIO_Input
PD2.GPIO_Label=LED_STATUS
PD2.Signal=GPIO_Output
PF0-OSC_IN.GPIO_Label=HSE_IN
PF0-OSC_IN.Signal=RCC_OSC_IN
PF1-OSC_OUT.GPIO_Label=HSE_OUT
PF1-OSC_OUT.Signal=RCC_OSC_OUT

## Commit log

2021-08-06 Add gain stage
2021-08-26 Remove gain stage
2021-08-26 Add KiCad and LTSpice files
    [STM32AudioEffects.kicad_pcb, STM32AudioEffects.sch, audio_io.sch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]
2021-09-08 Update main.c with FreeRTOS and board support
    Ported the superloop version to FreeRTOS, also added support for new board features (e.g., user inputs)
2021-09-08 Made minor changes to schematic

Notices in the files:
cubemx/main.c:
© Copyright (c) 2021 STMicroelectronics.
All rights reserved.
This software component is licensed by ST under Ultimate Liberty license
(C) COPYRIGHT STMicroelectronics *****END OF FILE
